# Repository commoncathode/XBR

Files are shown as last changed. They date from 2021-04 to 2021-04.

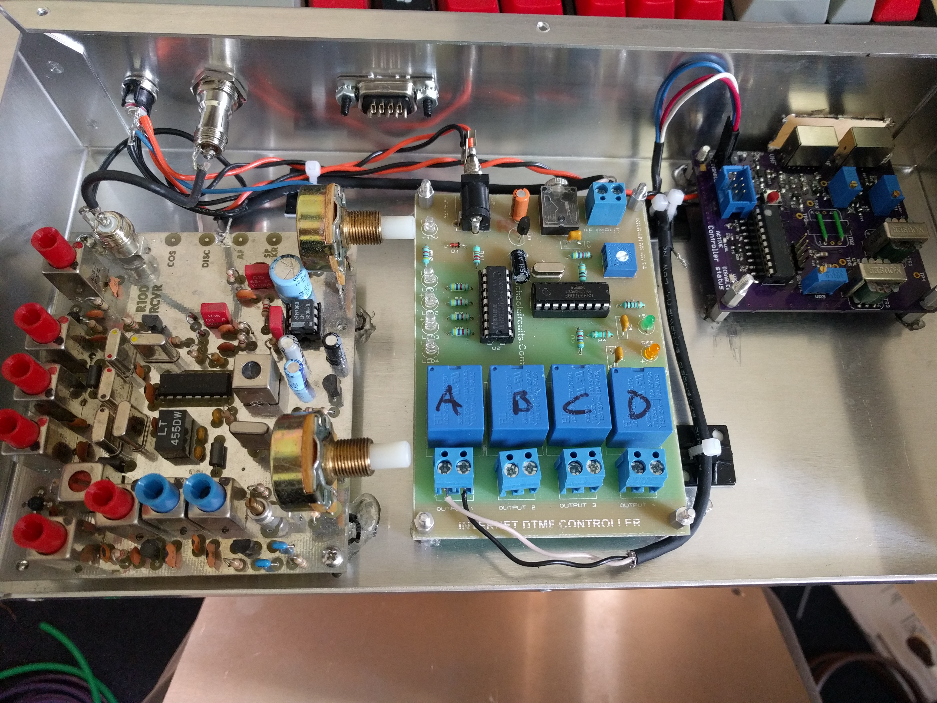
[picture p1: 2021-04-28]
IMG_20210428_132054.jpg

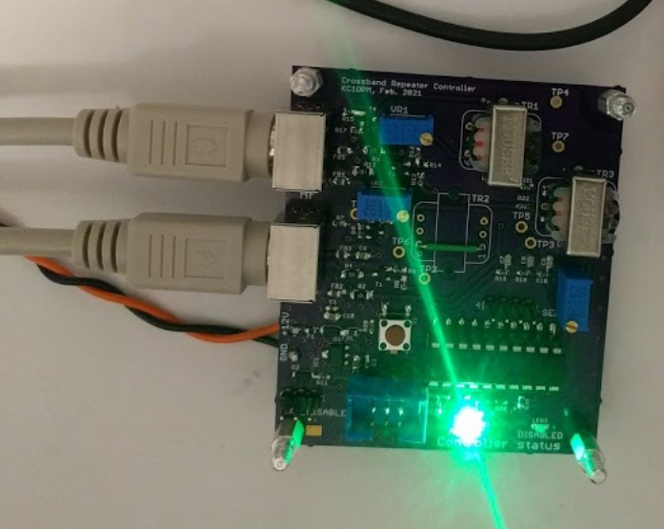
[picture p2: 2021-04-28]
board.PNG

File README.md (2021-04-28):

# XBR
The XBR is a cross-band repeater controller, intended for use with amateur radio transceivers. The radio ports are designed to work with the Yaesu FT-891 and Motorola XTL5000, but the circuitry is generic enough that, with some adjustment, it may very well work with a variety of radio transceivers. The heart of the controller is a Freescale/NXP 8-bit microcontroller, the MC9S08SH8.

**Background**

The main idea for this interface arose from the public service aspect of amateur (or "ham") radio. My club did a lot of public service events before the pandemic, such as foot and bike races. One event we were requested to assist with had a race course that covered much of the state, and so the differing terrain would make it difficult to maintain radio contact with the club's VHF repeater system. To fill in the weak spots, we thought "well, what about low band VHF, or even HF?" And I started to think, "better yet, what if all stations could hear one another, even if they were operating on a different band?" Thus, this interface is designed to link an HF/50 MHz radio to a VHF radio, in order to cross-link a VHF repeater onto an HF simplex frequency. Ideally, 28 or 50 MHz FM simplex linked to a 144 or 440 MHz repeater or repeater system.

**Operation**

Version 1 of the interface (or controller) is extremely simple in operation, designed to simply pass radio traffic automatically between two transcievers. It is not capable of linking repeaters or connecting to AllStar/Echolink. There is an impolite ID function that transmits on both radios every 10 minutes, non-adjustable. The tail is 500mS, non-adjustable. The ID function may be suitable for most users, but please follow your local governance for amateur radio operation. As I am in the US, the controller includes an active-low contact for disabling the repeater remotely to comply with FCC Part 97 regulations. There are many features I wish to add, but the intent was to develop a working, robust interface that provided reliable, legal operation of a cross-band repeater system at a base level.

**Revisions**

A few features I hope to add in the future are as follows.
- Capability to adjust all parameters over a serial terminal, such as:
- Call sign
- Tail length
- Polite ID function
- ID inactivity timer
- ID speed and pitch adjustment in words per minute (beta)
- Timeout timer length
- Enable/disable repeater over serial
- PTT and COR logic (active hi/lo)

**Errors**

1) With the components installed as outlined in the BoM, the ID function does not correctly pass audio to the mic inputs. You get sort of a "thumping" instead of a sine wave at 440Hz. This may be due to a low output impedance of the transformer coupled with the 10k resistors on the output; I am in the process of testing and verifying a few different solutions. 
2) The ID transformer's input is not referenced to common. I suggest scratching off some soldermask on the bottom next to the pad and bridging one side to the GND pour.
3) Impedance mismatch on the VHF port's mic circuit - just decoupled DC with a 4.7uF cap and jumped input to output in place of transformer TR2. This was an oddity with the radio I was using, so YMMV. 
Please view the schematic file or PDF print for a complete list of errata. 

Licensing is CC-BY-NC so please credit the author. Thanks!

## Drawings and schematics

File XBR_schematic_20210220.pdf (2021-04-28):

A

A

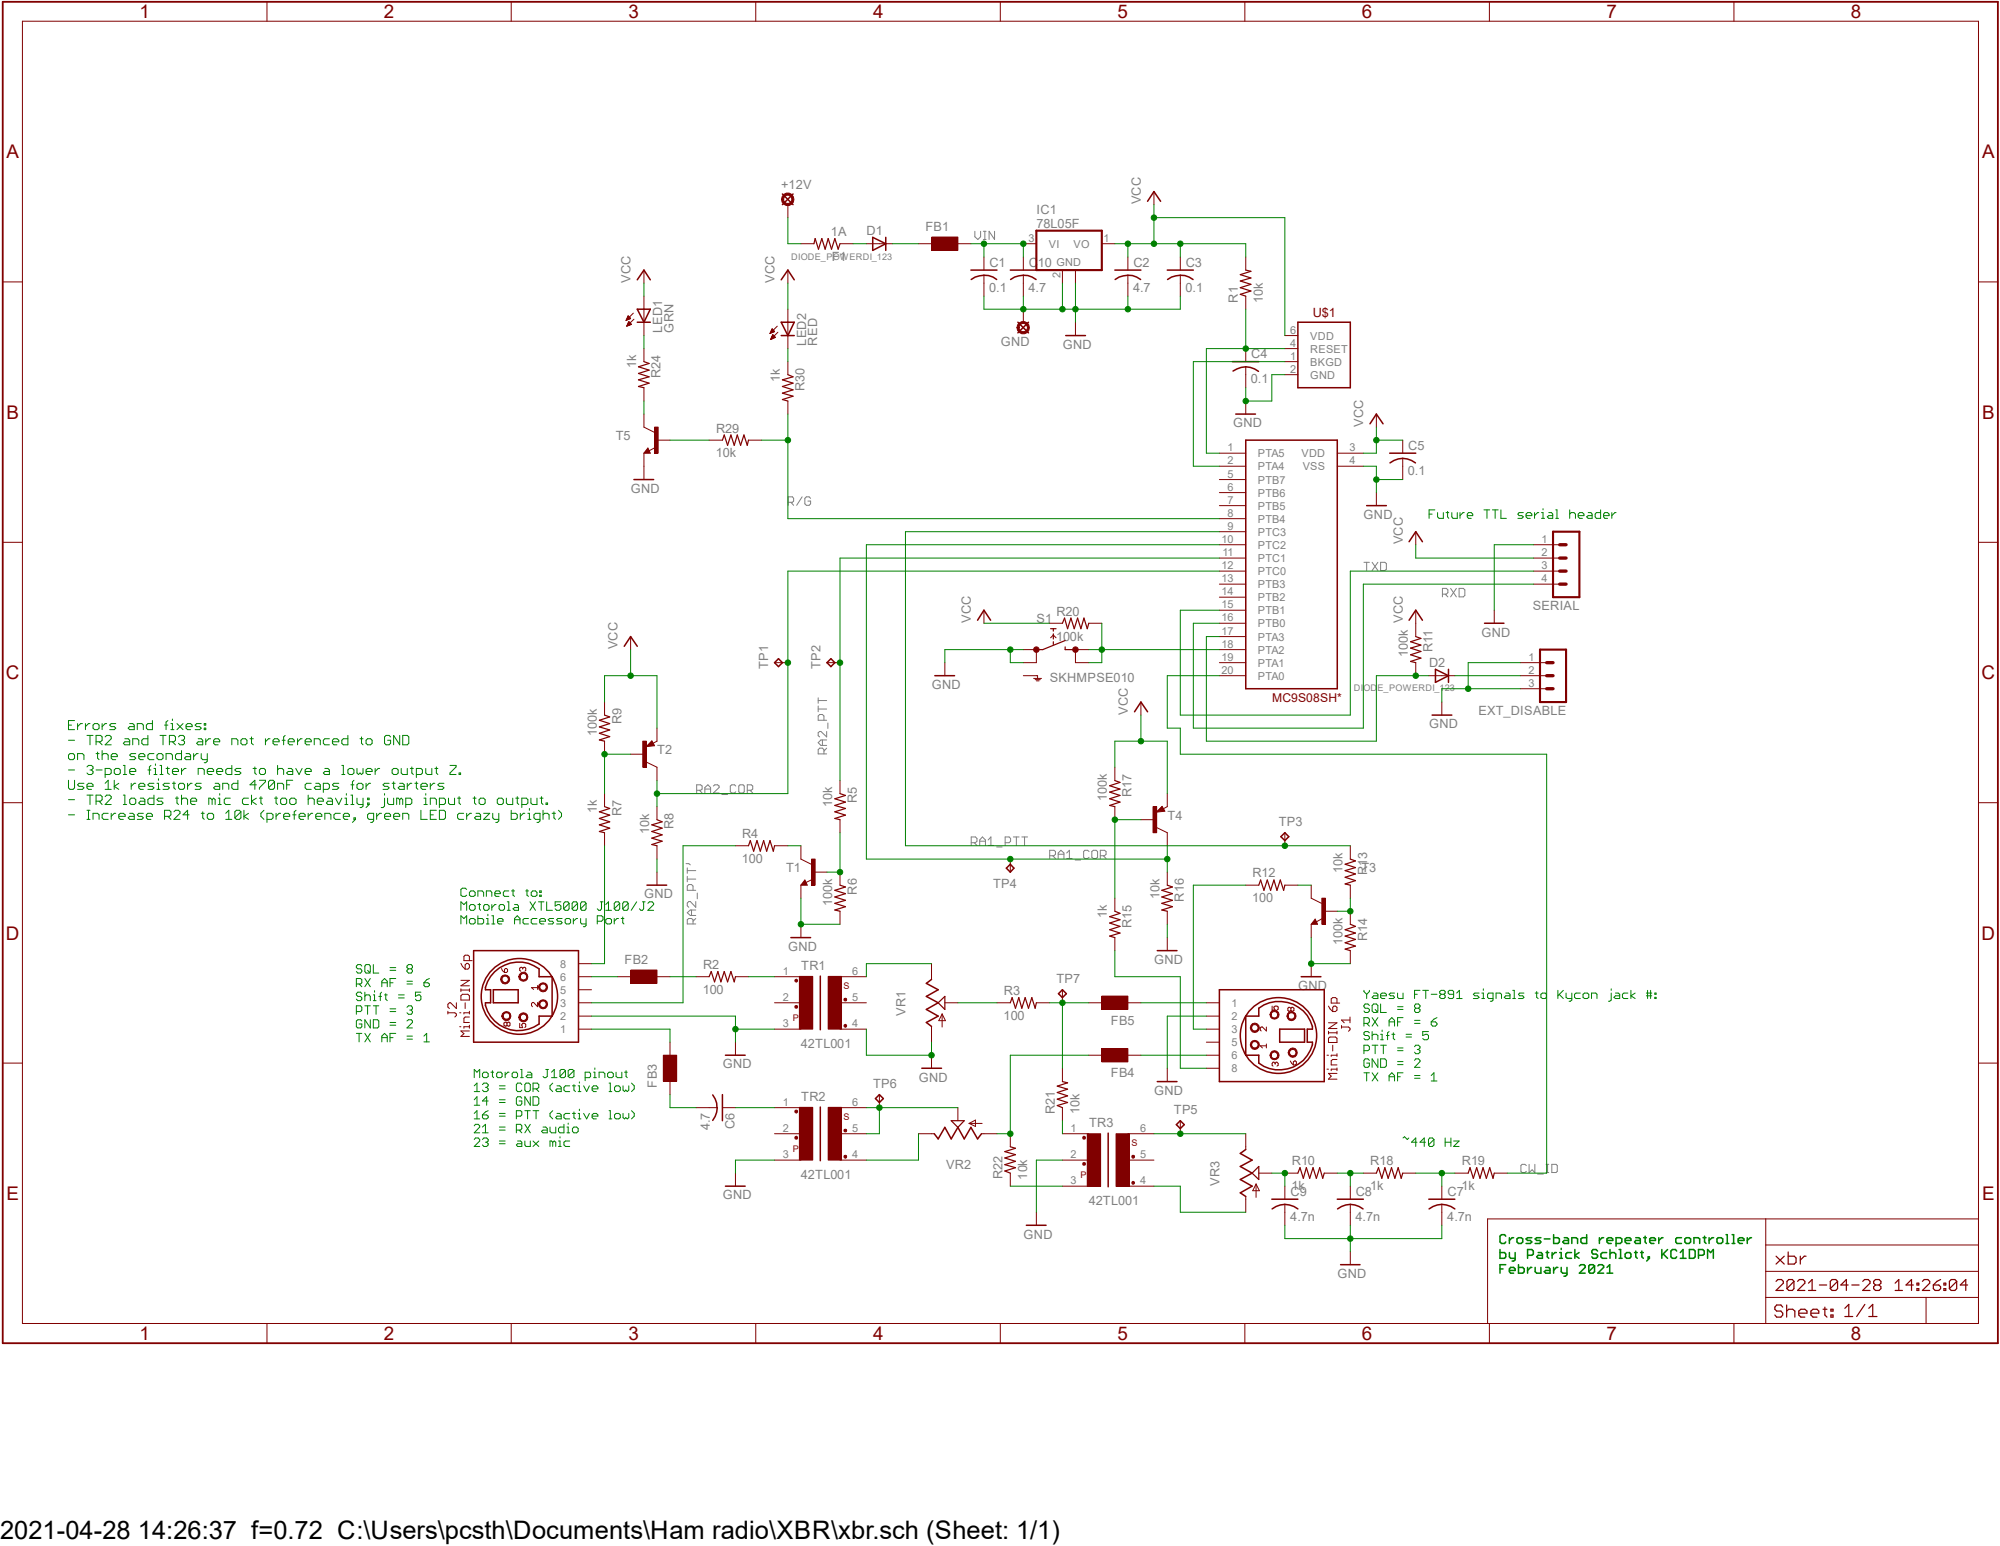
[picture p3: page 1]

PTA3 17

PTA1 19

2021-04-28 14:26:37 f=0.72 C:\Users\pcsth\Documents\Ham radio\XBR\xbr.sch (Sheet: 1/1)

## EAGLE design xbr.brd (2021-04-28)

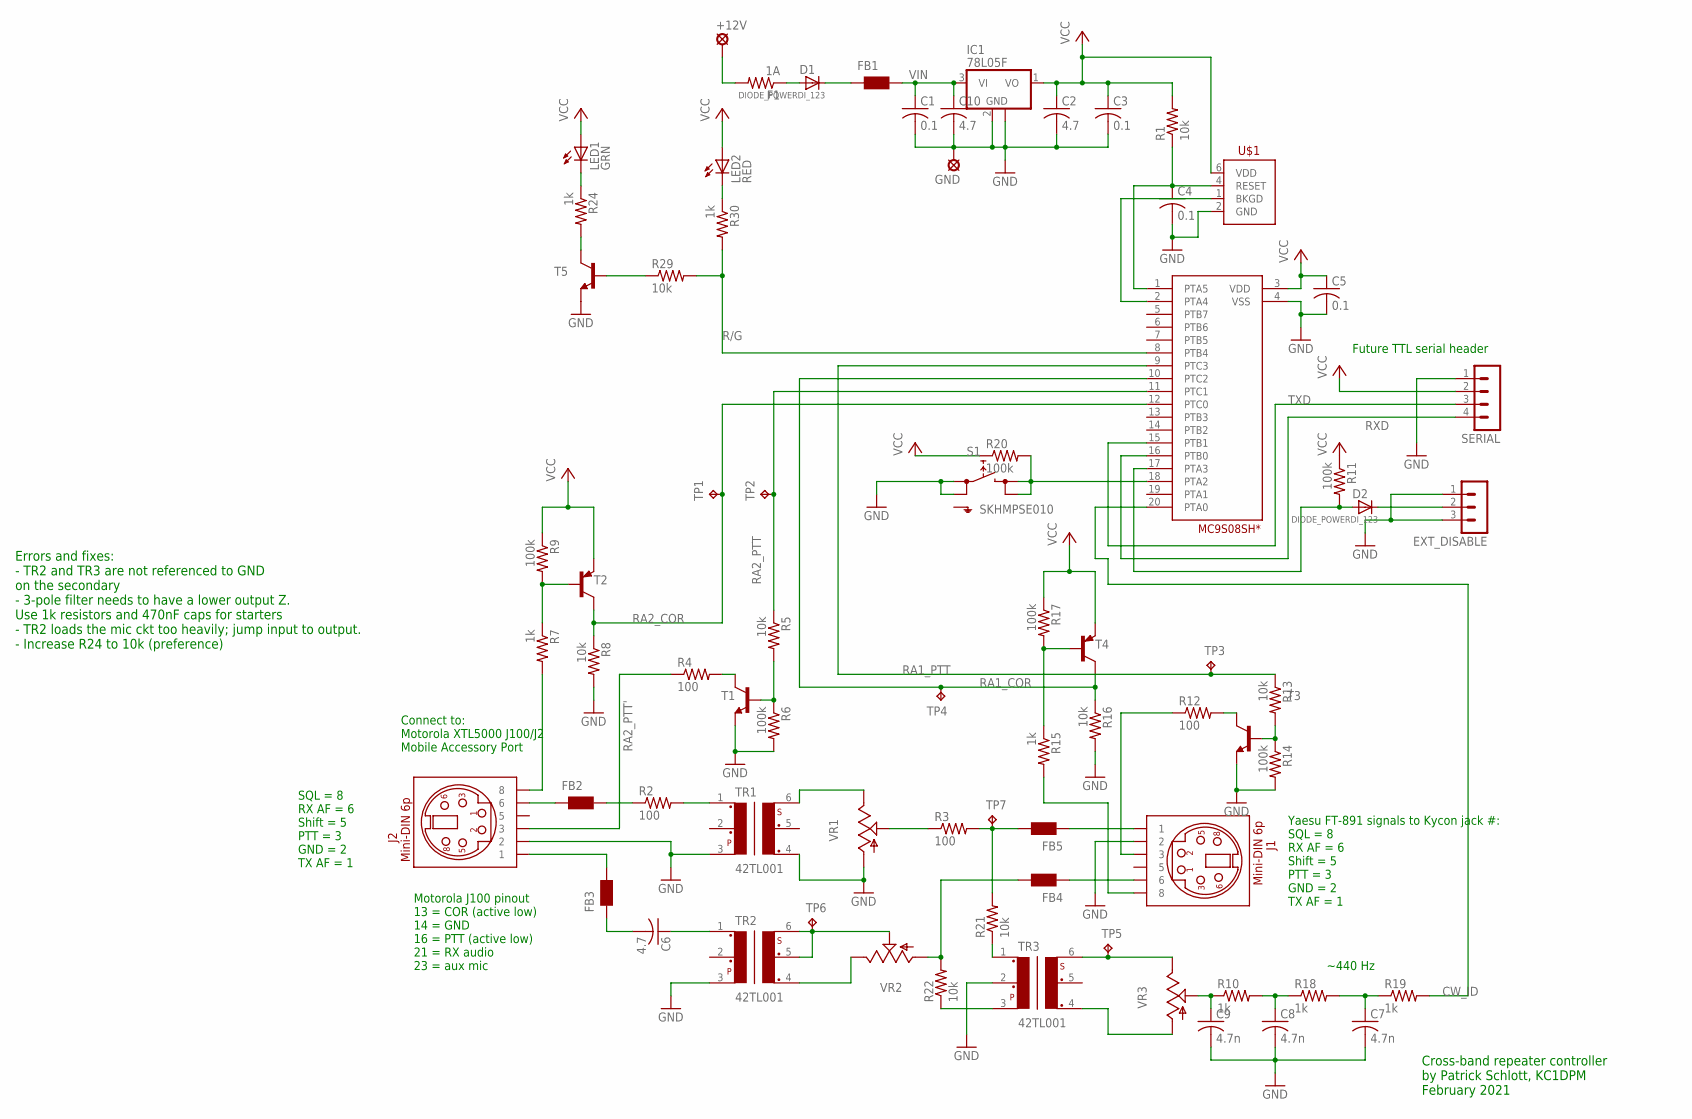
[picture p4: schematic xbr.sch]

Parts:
+12V: LSP10
C1, C3, C4, C5: 0.1; C0603
C2, C6, C10: 4.7; C0805
C7, C8, C9: 4.7n; C0603
D1, D2: DIODE_POWERDI_123; POWERDI_123
EXT_DISABLE: MA03-1
F1: 1A; R0603
FB1, FB2, FB3, FB4, FB5: WE-CBF_0805; 0805
GND: LSP10
IC1: 78L05F; SOT89
J1, J2: MINIDIN-6P; KMDTX-HT-6S-BSC
LED1: GRN; CHIPLED_0603
LED2: RED; CHIPLED_0805
R1, R5, R8, R13, R16, R21, R22, R29: 10k; R0603
R2, R3, R4, R12: 100; R1206
R6, R9, R11, R14, R17, R20: 100k; R0603
R7, R10, R15, R18, R19, R24, R30: 1k; R0603
S1: SKHMPSE010; SKHMPXE010
SERIAL: MA04-1
T1, T3, T5: MMBT2222ALT1-NPN-SOT23-BEC; SOT23-BEC
T2, T4: MMBT3906LT1-PNP-SOT23-BEC; SOT23-BEC
TP1, TP2, TP3, TP4, TP5, TP6, TP7: TPPAD1-13; P1-13
TR1, TR2, TR3: 42TL001; 42TL
U$1: BDM_HEADER; 2X03
U$2: MC9S08SH; PDIP-20
VR1, VR2, VR3: TRIM_US-B64Y; B64Y

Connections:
CW_ID: R19.2, U$2.20 (PTA0)
GND: C1.2, C2.2, C3.2, C4.2, C5.2, C7.2, C8.2, C9.2, C10.2, EXT_DISABLE.1, EXT_DISABLE.3, GND.MP, IC1.2 (GND), IC1.2@1 (GND), J1.2-GND (2), J2.2-GND (2), R6.2, R8.2, R14.2, R16.2, S1.1 (1.1), S1.2 (1.2), SERIAL.1, T1.E, T3.E, T5.E, TR1.3, TR1.4, TR2.3, TR3.2, U$1.2 (GND), U$2.4 (VSS), VR1.A
unnamed: C4.1, R1.1, U$1.4 (RESET), U$2.1 (PTA5)
unnamed: J2.8-SQL/COR (8), R7.2
unnamed: U$1.1 (BKGD), U$2.2 (PTA4)
unnamed: FB2.2, R2.1
unnamed: R2.2, TR1.1
unnamed: R7.1, R9.2, T2.B
unnamed: D1.K (C), FB1.1
unnamed: TR1.6, VR1.E
unnamed: R21.1, TR3.1
unnamed: R3.1, VR1.S
unnamed: FB5.2, R3.2, R21.2, TP7.TP
unnamed: TR2.4, VR2.E
unnamed: TP6.TP, TR2.5, TR2.6, VR2.S
unnamed: FB4.2, R22.2, VR2.A
unnamed: C6.1, TR2.1
unnamed: TP5.TP, TR3.6, VR3.E
unnamed: FB3.2, J2.1-DATA_IN (1)
unnamed: TR3.4, VR3.A
unnamed: R4.2, T1.C
unnamed: R5.2, R6.1, T1.B
unnamed: C9.1, R10.1, VR3.S
unnamed: D2.K (C), EXT_DISABLE.2
unnamed: D2.A, R11.2, U$2.17 (PTA3)
unnamed: R12.2, T3.C
unnamed: R13.2, R14.1, T3.B
unnamed: J1.8-SQL/COR (8), R15.2
unnamed: R15.1, R17.2, T4.B
unnamed: R20.2, S1.3 (2.1), S1.4 (2.2), U$2.18 (PTA2)
unnamed: R22.1, TR3.3
unnamed: C7.1, R18.2, R19.1
unnamed: C8.1, R10.2, R18.1
unnamed: LED1.C, R24.1
unnamed: R24.2, T5.C
unnamed: LED2.C, R30.1
unnamed: FB2.1, J2.6-DATA_OUT (6)
unnamed: R29.1, T5.B
unnamed: C6.2, FB3.1
unnamed: D1.A, F1.1
unnamed: +12V.MP, F1.2
unnamed: FB4.1, J1.6-DATA_OUT (6)
unnamed: FB5.1, J1.1-DATA_IN (1)
R/G: R29.2, R30.2, U$2.8 (PTB4)
RA1_COR: R16.1, T4.C, TP4.TP, U$2.10 (PTC2)
RA1_PTT: R13.1, TP3.TP, U$2.9 (PTC3)
RA1_PTT': J1.3-PTT (3), R12.1
RA2_COR: R8.1, T2.C, TP1.TP, U$2.12 (PTC0)
RA2_PTT: R5.1, TP2.TP, U$2.11 (PTC1)
RA2_PTT': J2.3-PTT (3), R4.1
RXD: SERIAL.4, U$2.16 (PTB0)
TXD: SERIAL.3, U$2.15 (PTB1)
VCC: C2.1, C3.1, C5.1, IC1.1 (VO), LED1.A, LED2.A, R1.2, R9.1, R11.1, R17.1, R20.1, SERIAL.2, T2.E, T4.E, U$1.6 (VDD), U$2.3 (VDD)
VIN: C1.1, C10.1, FB1.2, IC1.3 (VI)

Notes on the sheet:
Yaesu FT-891 signals to Kycon jack #: SQL = 8 RX AF = 6 Shift = 5 PTT = 3 GND = 2 TX AF = 1
Connect to: Motorola XTL5000 J100/J2 Mobile Accessory Port
Motorola J100 pinout 13 = COR (active low) 14 = GND 16 = PTT (active low) 21 = RX audio 23 = aux mic
SQL = 8 RX AF = 6 Shift = 5 PTT = 3 GND = 2 TX AF = 1
Future TTL serial header
Cross-band repeater controller by Patrick Schlott, KC1DPM February 2021
~440 Hz
Errors and fixes: - TR2 and TR3 are not referenced to GND on the secondary - 3-pole filter needs to have a lower output Z. Use 1k resistors and 470nF caps for starters - TR2 loads the mic ckt too heavily; jump input to output. - Increase R24 to 10k (preference)

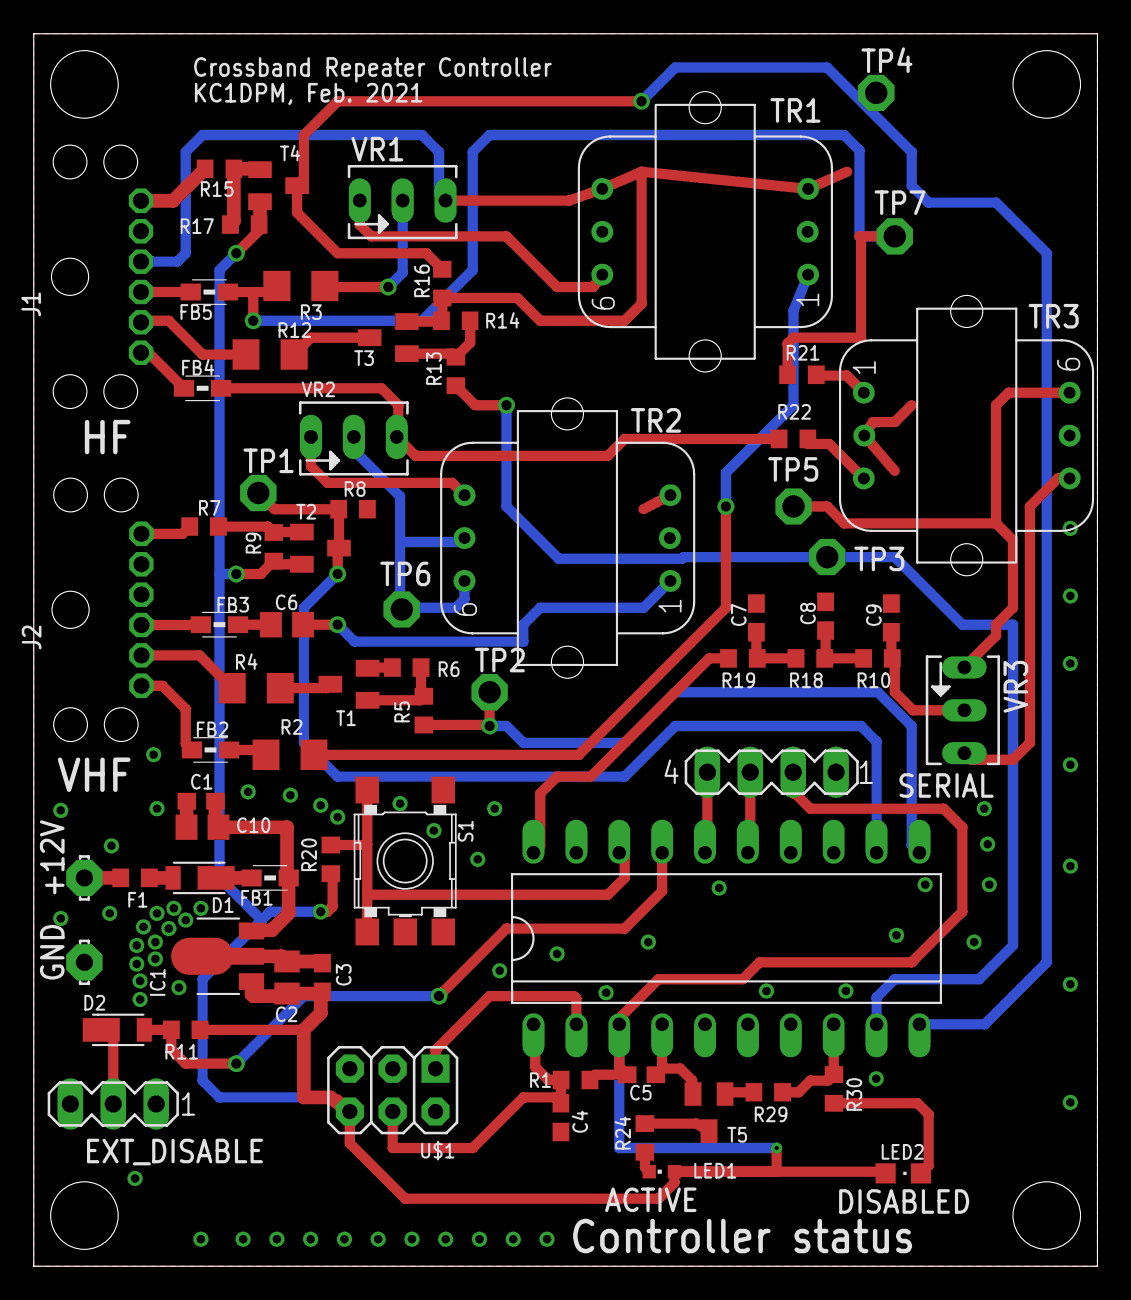
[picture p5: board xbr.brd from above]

Board: 2 copper layers, 63.0 x 73.0 mm, 73 parts (0 on the bottom side), 54 nets.

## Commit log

2021-04-28 Adding pcb files, schematic and bom
    Important files for version 1 of the board. The PCB file has some errors, but the fixes and details are listed in the schematic.
    Firmware available upon request only.
    [xbr.brd, xbr.sch]
2021-04-28 Added pictures
    Included populated circuit board plus custom project box with VHF receiver and DTMF relay board
2021-04-28 Added board pic
